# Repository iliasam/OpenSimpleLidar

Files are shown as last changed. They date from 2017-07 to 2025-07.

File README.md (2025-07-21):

# OpenSimpleLidar
Open Hardware scanning laser rangefinder.  
Its parameters:  
* 5 scans/second
* 180 measurements per rotation (2 deg anglular resolution)
* Maximum distance - 4 m
* Measured accuracy ~3-5 cm at 3 m (depends upon the color of reflecting surface).

This device is really cheap - its components cost less than $30.  
**UPD from 2023: Cost of the image sensor TSL1401CL increased very much, so total price can be higher!**  
See "TotalBOM" with price calculations.  
  
See project wiki for more info: https://github.com/iliasam/OpenSimpleLidar/wiki  

[Please take the simple survey about assembling instructions](https://docs.google.com/forms/d/127PN3ydydF8poReQAPeC-vXDqIst-CIAj8u08tnh1lM)  
  
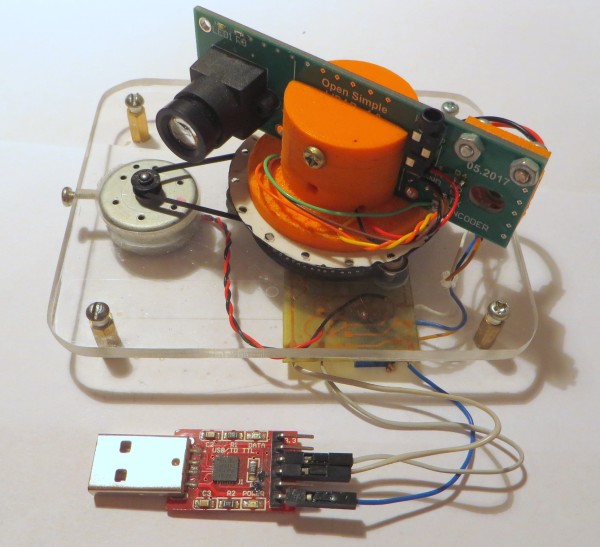
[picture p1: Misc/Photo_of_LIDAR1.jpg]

  
Utility for displaying "radar" scans from the working Lidar:  
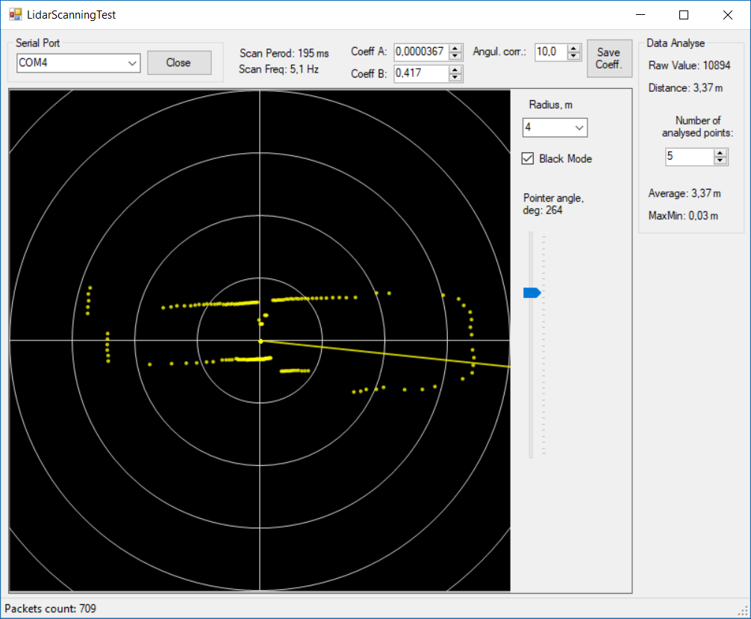
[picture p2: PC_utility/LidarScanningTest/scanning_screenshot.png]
  

Example of Hector SLAM working with this Lidar:  
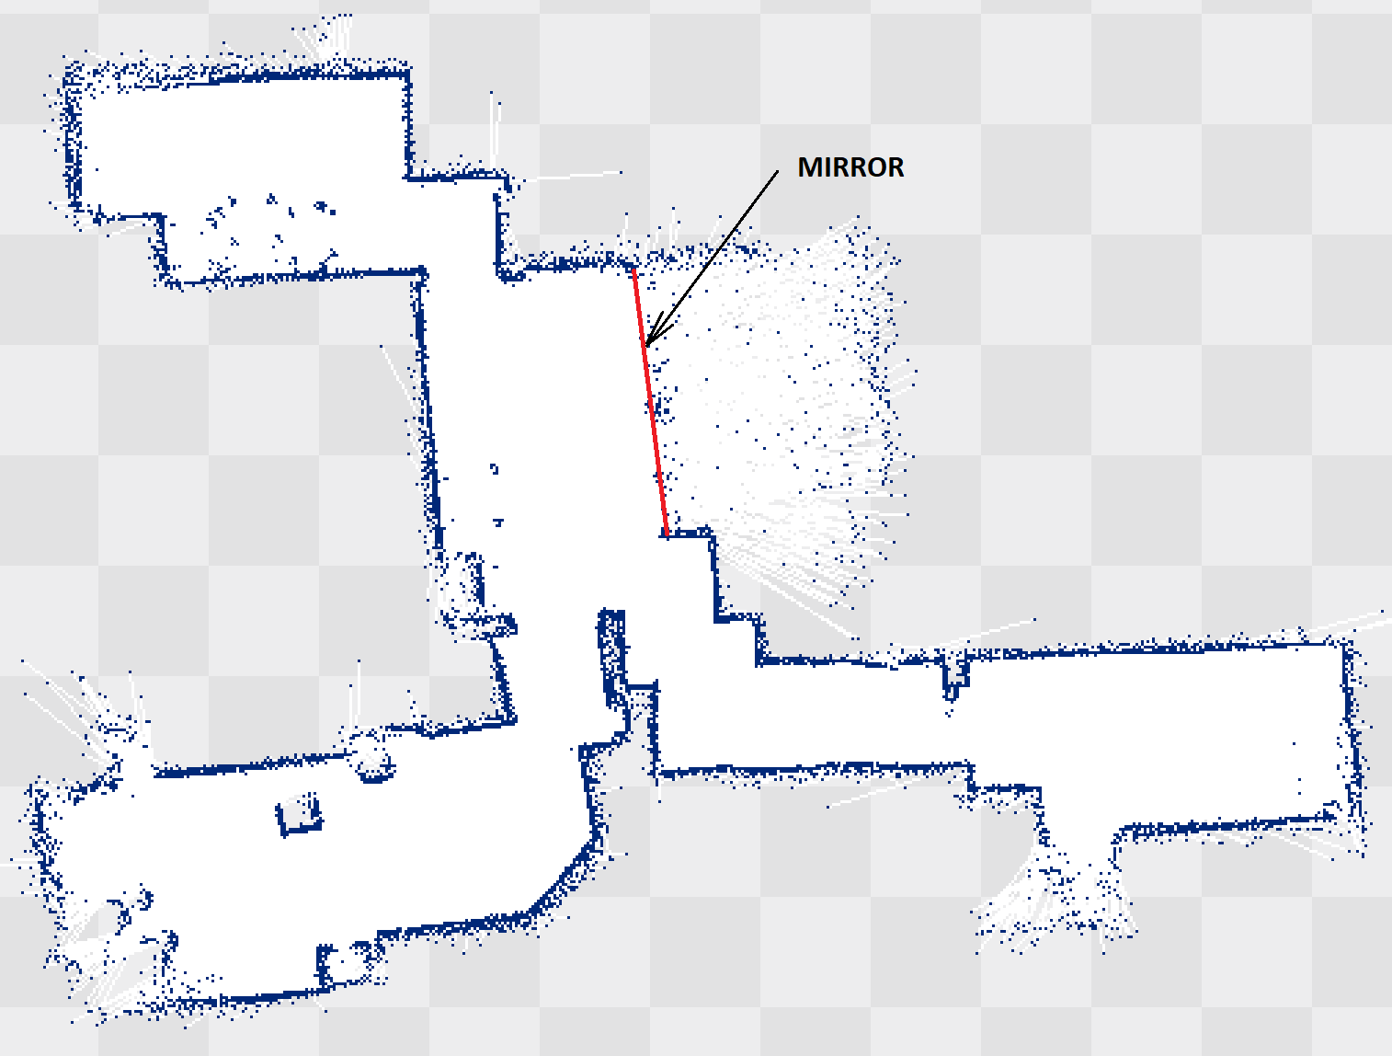
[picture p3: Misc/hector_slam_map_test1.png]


This Lidar is using **triangulation method** for measuring distance to objects. It can be shown by this picture:  
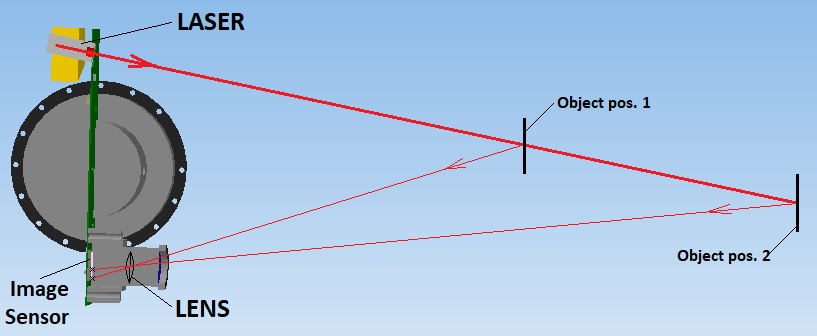
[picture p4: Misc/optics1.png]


Some modeled pictures of the assembled Lidar can be found here: https://github.com/iliasam/OpenSimpleLidar/tree/master/Misc/Pictures/  

Some more info: https://hackaday.io/project/20628-opensimplelidar  

Video of using OpenSimpleLidar for Autonomous Robot Navigation:  
https://www.youtube.com/watch?v=YHt_NTktmlA

See also my previous LIDAR project: https://github.com/iliasam/OpenLIDAR  
If you need LIDAR with increased speed and range, see this project: https://github.com/iliasam/OpenTOFLidar  

Please leave your feedback if you will be able to build this Lidar - I need more feedback about assembing instructions.

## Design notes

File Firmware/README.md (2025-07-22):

"test_encoder_blinking" - Testing code - link LED several times after power up, and then blinking LED when encoder event occurs.   
"test1_capture_image" - Testing code - capture image from linear image sensor and send it to PC.  
"test2_capture_image" - Testing code - the same as "test1_capture_image" but laser is ON most of the time. This is MORE dangerous for eyes than "test1_capture_image"!  
"lidar4_main_code" - Main LIDAR firmware.  

UART protocols are described here: https://github.com/iliasam/OpenSimpleLidar/wiki/Lidar-UART-Protocol  
  
IAR 7.50 could be used for building projects.  
You can find already build HEX files at the "EWARM/Output/Exe" folders.

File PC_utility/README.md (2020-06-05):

"LidarRawDataCapture.exe" - utility for displaying raw data from the TSL1401. This utility must be used with "test1_capture_image" firmware. It is needed during laser alignment.
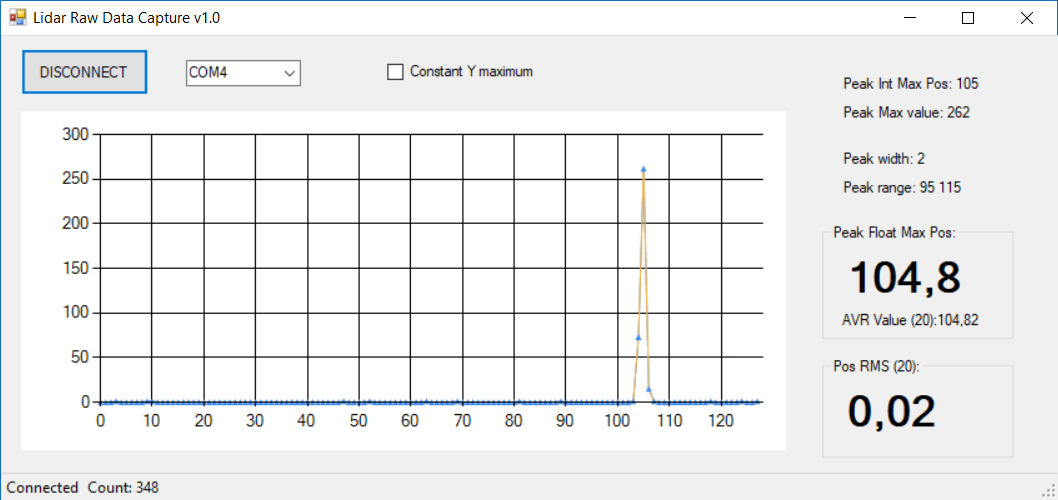
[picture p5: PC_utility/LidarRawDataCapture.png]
  

"LidarScanningTest" - utility for displaying "radar" scans from the working Lidar. This utility must be used with "lidar4_main_code" firmware.  
  

Values "Coeff A", "Coeff B" are calibration values. They are unique for every device.  
Track bar allows to set "Pointer angle" - angle of the long yellow line.  
Parameters of the point with that angle are displayed at "Data Analyse" group.  
This utility is published with its source files.  
"Exe" is placed here: https://github.com/iliasam/OpenSimpleLidar/tree/master/PC_utility/LidarScanningTest/LidarScanningTest1/bin/Debug

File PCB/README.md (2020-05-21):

## OpenSimpleLidar PCB and schematic.  
Important notice: I did not tested "CommonPCB_v1.1M", "CommonPCB_v1.2"  "MainPCB_v1.1"!  

Boards "MainPCB_v1.0"/"MainPCB_v1.1" should be used with "MotorPCB_v1.0".  

Board "CommonPCB_XX.XX" contains motor board, so you must split motor board and main board (by cutting by white line).  
Total width of the "CommonPCB_XX.XX" is 99mm, height is 26mm.  
PCB thickness - 1.6 mm.  
Board "CommonPCB_v1.2" have improved connections for the slip ring wires - now they are holes.  
Board "CommonPCB_v1.2M" - version for M12 lens holder with 20mm hole distance.  

## Схема и печатная плата OpenSimpleLidar
Внимание - я не изготавливал версии плат "CommonPCB_v1.1M" и "MainPCB_v1.1"!
Платы "MainPCB_v1.0" и "MainPCB_v1.1" нужно использовать с отдельной платой "MotorPCB_v1.0".  
Плата "CommonPCB_v1.1M" уже содержит в себе плату мотора, 
так что плату мотора нужно аккуратно отрезать от главной платы перед сборкой.
Общая ширина платы "CommonPCB_v1.1M" - 99 мм, высота - 26 мм.  
Толщина платы - 1.6 мм.

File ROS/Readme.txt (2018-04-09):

"roomba_lidar" is Open Hardware Lidar node for ROS.

Important notice - you need to specify "a_coef" and "b_coef" in *.launch file. This parameters calculated during lidar calibration.
Also you need to specify "port" parameter.

This code is partially taken from this project: http://wiki.ros.org/xv_11_laser_driver/

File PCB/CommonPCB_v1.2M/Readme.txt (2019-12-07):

Project files - PCB and schematic.  
Note that I don't test them.
V1.2M - version for M12 lens holder with 20mm hole distance.
There are no changes in schematic against "v1.2" PCB.
See assembling pictures in "CommonPCB_v1.2" folder.

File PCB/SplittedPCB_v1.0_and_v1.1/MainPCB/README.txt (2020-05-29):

Main board PCB.   
Gerber_files_v1.0 - 05.2017  
Gerber_files_v1.1 - 03.2018  
Important notice - I did not tested PCB v 1.1!

v1.1 differences from v1.0:
* Added J2 connectror fo programming via SWD.
* Added TEST2 pad

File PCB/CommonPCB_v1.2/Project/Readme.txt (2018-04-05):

Project files - PCB and schematic.  
Note that I don't test them.

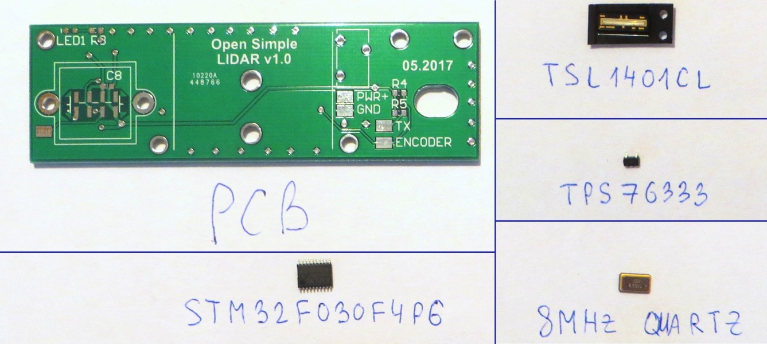
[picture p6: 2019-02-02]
Misc/Pictures/pcb_electronics.jpg

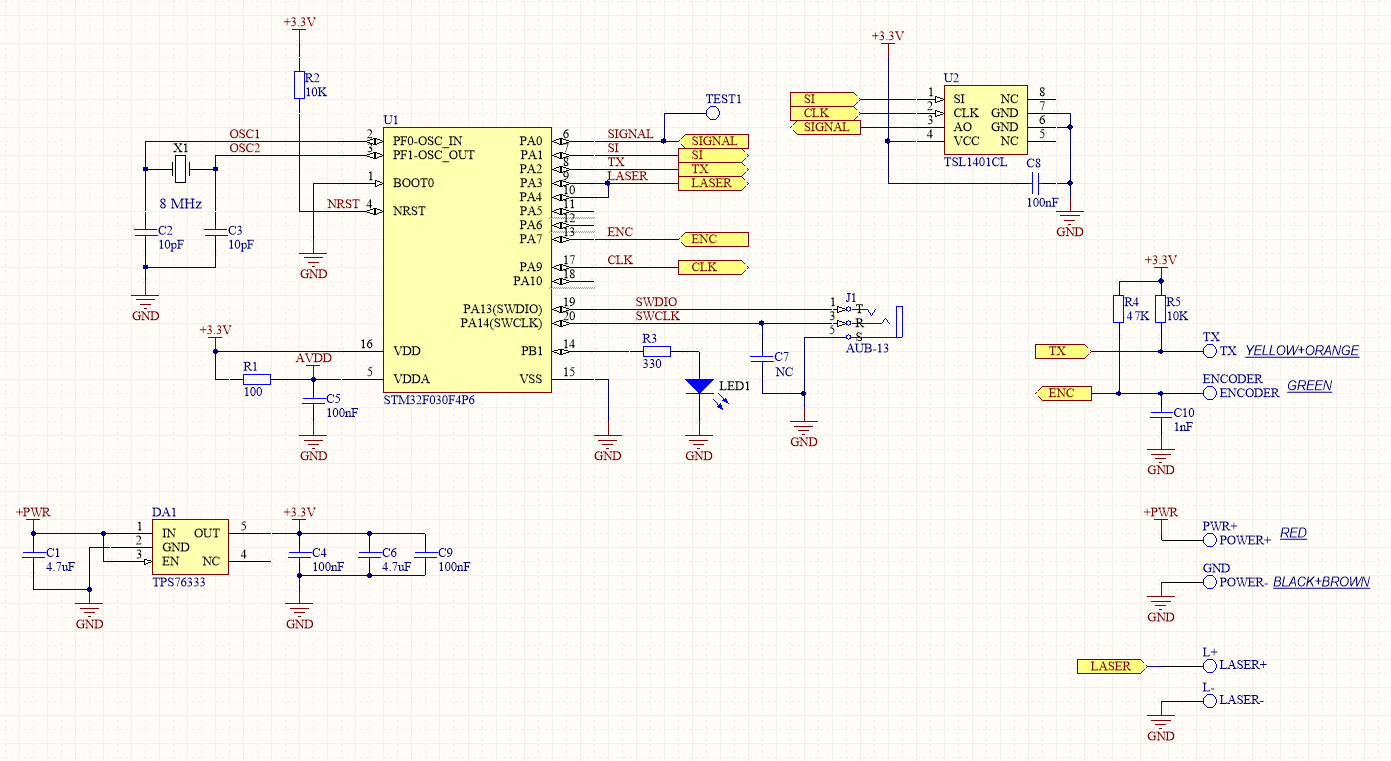
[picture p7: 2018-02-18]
PCB/SplittedPCB_v1.0_and_v1.1/MainPCB/Schematic_v1.png

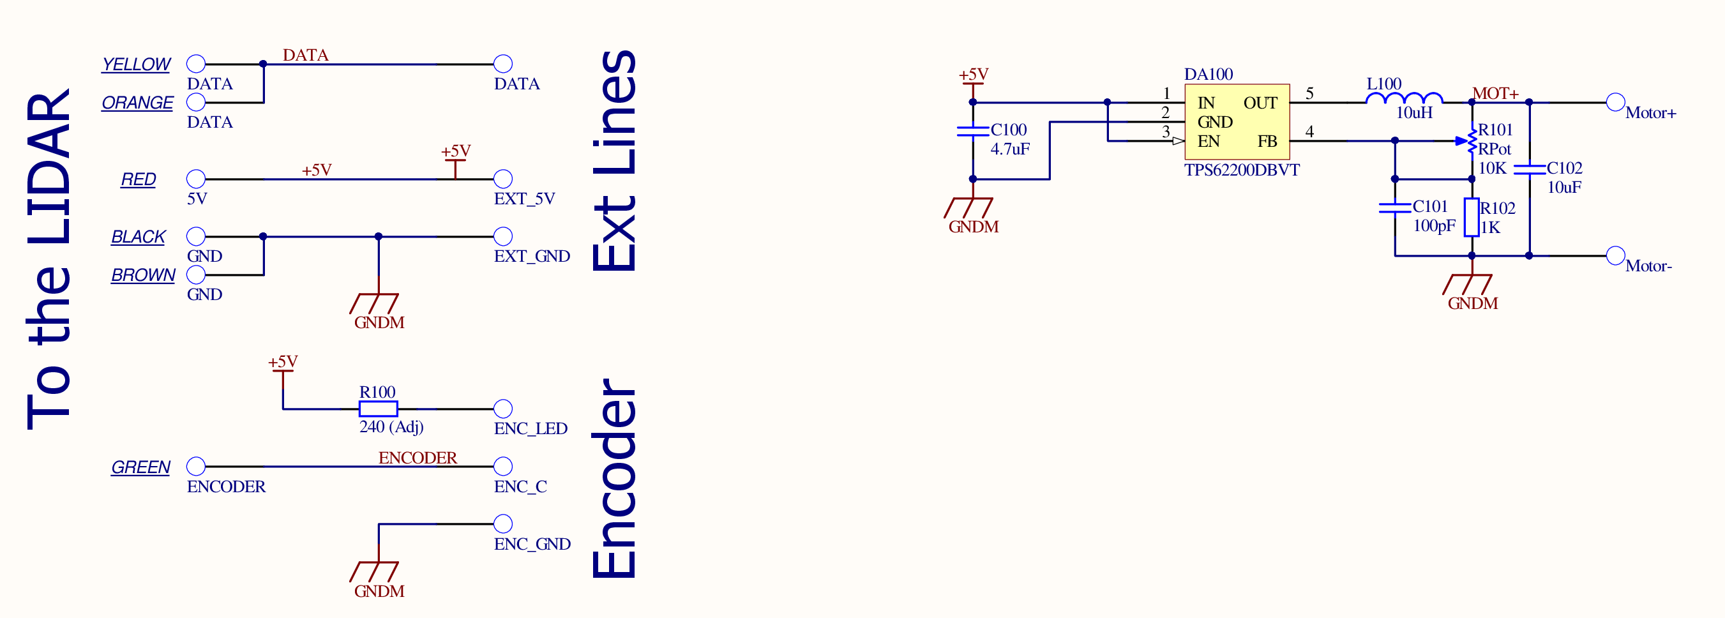
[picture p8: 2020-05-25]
PCB/CommonPCB_v1.2/Schematic_motor_v1.2.png

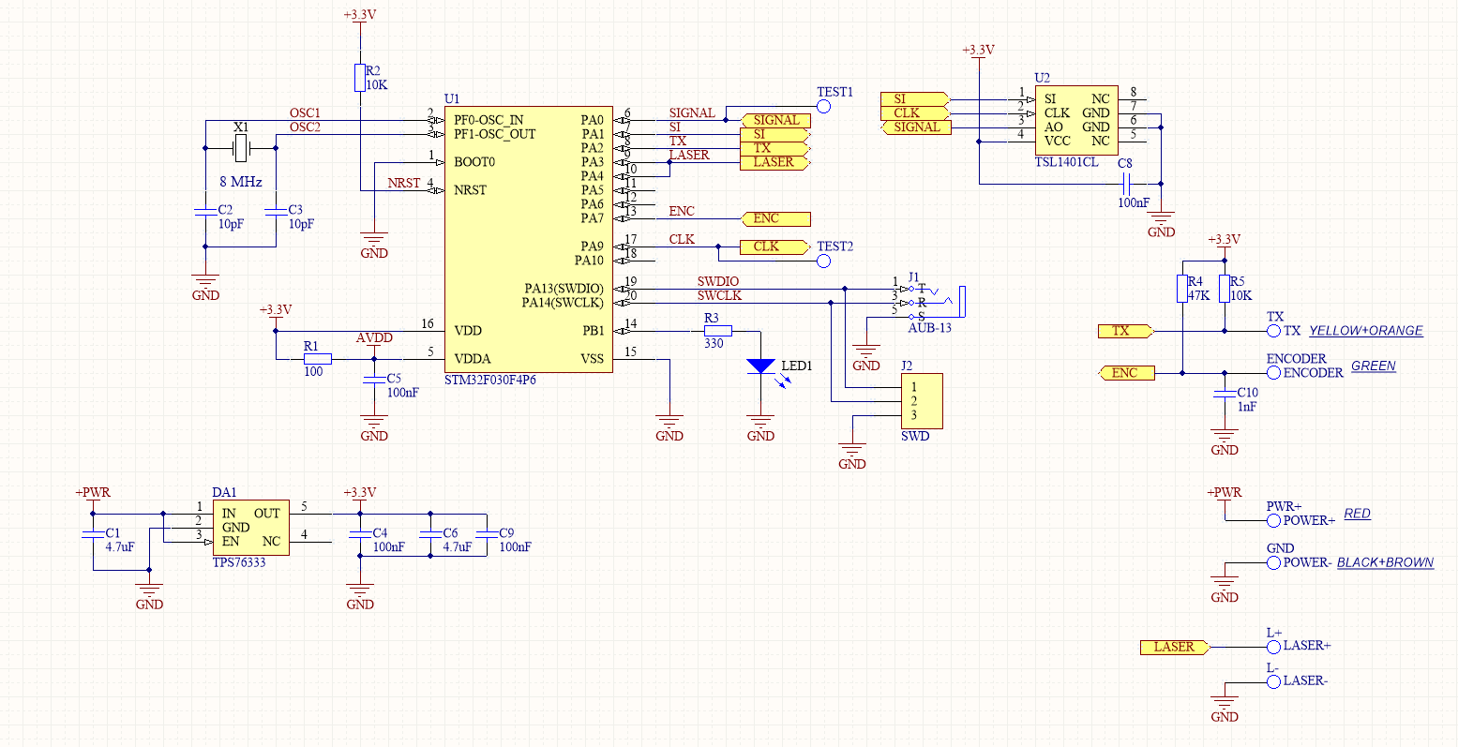
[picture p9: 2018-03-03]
PCB/SplittedPCB_v1.0_and_v1.1/MainPCB/Schematic_v1_1.png

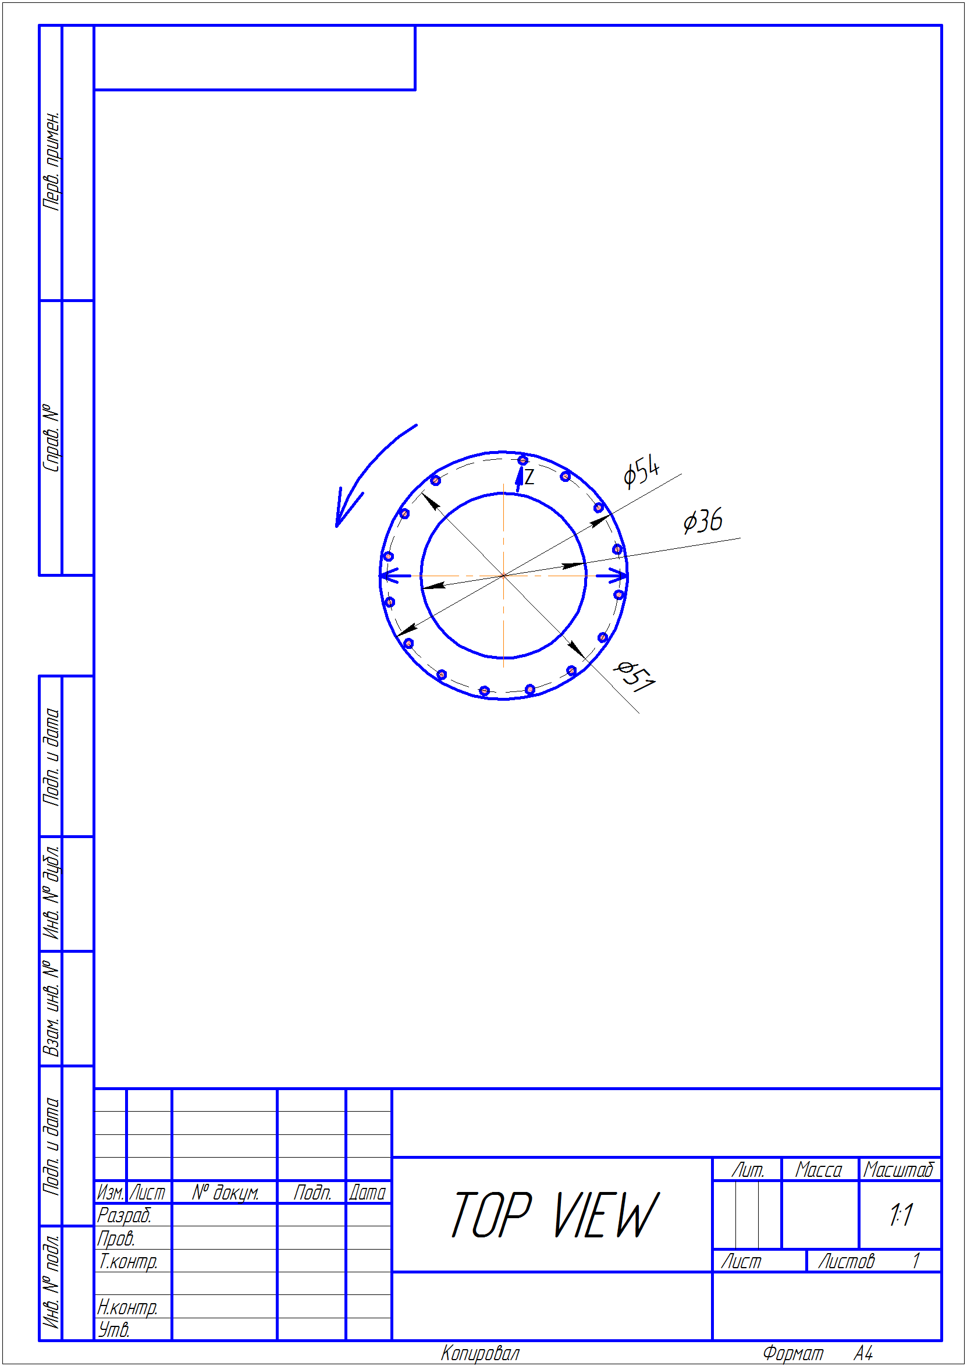
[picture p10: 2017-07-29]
Mechanics/Encoder_ring/Encoder_ring.png

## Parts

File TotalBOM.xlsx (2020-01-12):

 | No. | Name | Price | Description | URL
PCB components | 1 | Laser | $2.75 | 3mw 780nm Infrared IR Diode | http://www.ebay.com/itm/322300023463
 | 2 | Lens | $4.00 | M12 lens, f'=16mm, 1/3'', F2.0 | https://world.taobao.com/item/4526951102.htm
 | 3 | Interference filter (OPTIONAL) | $6.00 | 780nm IR Bandpass filter 8.0*8.0mm | http://www.ebay.com/itm/2pcs-Optical-Interference-Filter-780nm-IR-Bandpass-filter-8-0-8-0mm-/252299157201
 | 4 | Lens holder | $0.50 | M12 Lens holder (18 mm) | https://world.taobao.com/item/19038223269.htm
 |  |  |  | OR M12 Lens holder (20 mm) | for "CommonPCB_v1.2M"
 | 5 | PCB | $2.00 | Main PCB board - 1.6mm 2 layers. Price for 10 boards. | https://jlcpcb.com/quote
 | 6 | TSL1401CL | $6.00 | Image sensor | https://www.aliexpress.com/
 | 7 | MCU | $0.60 | STM32F030F4P6 - price for single chip. | https://www.aliexpress.com/item/Free-shipping-10pcs-STM32F030F4P6-Value-line-ARM-based-32-bit-MCU-STM32F030F4P6/32399890554.html
 | 9 | Slip Ring | $2.82 | 12.5mm 300Rpm 6 Wires Slip Ring (SRM-12-06a) | http://www.ebay.com/itm/141871384929
 | 10 | Motor | $1.00 | 3V DC motor
 | 11 | Ball bearing | $1.00 | 806ZZ type
 | 12 | Encoder sensor | $1.50 | RPI-352
 | 13 | Rubber belt | $1.00 | 150 mm - perimeter length
 | 14 | Pulley for motor |  | It could be taken form DVD
 |  | Total: | $29.17 | Note - this total price is calculated without delivery price
 |  |  | $23.17 | Price without filter

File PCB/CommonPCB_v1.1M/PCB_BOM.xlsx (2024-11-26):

Designator | Comment | Footprint | Description
C1 | 4.7uF | CAPC2012X135N | Chip capacitor
C2 | 10pF | CAPC1608X90N | Chip capacitor
C3 | 10pF | CAPC1608X90N | Chip capacitor
C4 | 100nF | CAPC1608X90N | Chip capacitor
C5 | 100nF | CAPC1608X90N | Chip capacitor
C6 | 4.7uF | CAPC2012X135N | Chip capacitor
C8 | 100nF | CAPC1608X90N | Chip capacitor
C9 | 100nF | CAPC1608X90N | Chip capacitor
C10 | 1nF | CAPC1608X90N | Chip capacitor
DA1 | TPS76333 | SOT23-5 | LDO
J1 | Jack 3.5 | AUB-13 | SWD connector
J2 | Header |  | Header, 3-Pin
LED1 | LED | 0603 | LED
R1 | 100 | RESC1608X55N | Chip resistor
R2 | 10K | RESC1608X55N | Chip resistor
R3 | 330 | RESC1608X55N | Chip resistor
R4 | 47K | RESC1608X55N | Chip resistor
R5 | 10K | RESC1608X55N | Chip resistor
U1 | STM32F030F4P6 | TSSOP65P640X120-20N | ARM-based 32-bit MCU
U2 | TSL1401CL | TSL1401CL | Light sensor
X1 | Quartz 8 MHz | SX-6 QUARTZ | Quartz_SX-6 (SMD06035C4)
Motor PCB
C100 | 4.7uF | CAPC2012X135N | Chip capacitor
C101 | 100pF | CAPC1608X90N | Chip capacitor
C102 | 10uF | CAPC3216X100N | Chip capacitor
L100 | Inductor 10uH | INDC3216 | Inductor
R100 | 240 Ohm (Adj) | RESC1608X55N | Chip resistor
R101 | Potentiometer 10K | VR5 | Potentiometer
R102 | 1K | RESC1608X55N | Chip resistor
DA100 | TPS62200DBVT | SOT23-5 | DC-DC step-down

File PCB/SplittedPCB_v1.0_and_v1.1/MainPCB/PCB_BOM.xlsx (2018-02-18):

# | Quantity | Designator | Footprint | Value | Description
1 | 2 | C1, C6 | CC0805 | 4.7uF | Chip capacitor
2 | 2 | C2, C3 | CC0805 | 10pF | Chip capacitor
3 | 4 | C4, C5, C8, C9 | CC0805 | 100nF | Chip capacitor
4 | 1 | C7 | CC0805 | NC | Chip capacitor
5 | 1 | DA1 | SOT23-5 | TPS76333 | LDO
6 | 1 | ENCODER |  | ENCODER | Pad for wire
7 | 1 | GND |  | POWER- | Pad for wire
8 | 1 | J1 | AUB-13 | AUB-13 | Programming connector
9 | 1 | L+ | Ext_hole | LASER+ | Pad for wire
10 | 1 | L- | Ext_hole | LASER- | Pad for wire
11 | 1 | LED1 | LED_0603 | LED
12 | 1 | PWR+ | Ext_pad | POWER+ | Pad for wire
13 | 1 | R1 | RC0805 | 100 | Chip resistor
14 | 2 | R2, R5 | RC0805 | 10k | Chip resistor
15 | 1 | R3 | RC0805 | 330 | Chip resistor
16 | 1 | R4 | RC0805 | 47k | Chip resistor
17 | 1 | TEST1 | Ext_pad | Pad | Pad for wire
18 | 1 | TX | Ext_pad | TX | Pad for wire
19 | 1 | U1 | TSSOP65P640X120-20N | STM32F030F4P6 | MCU
20 | 1 | U2 | TSL1401CL | TSL1401CL | Light sensor
21 | 1 | X1 | SX-6 QUARTZ | Quartz | Quartz_SX-6 (SMD06035C4)

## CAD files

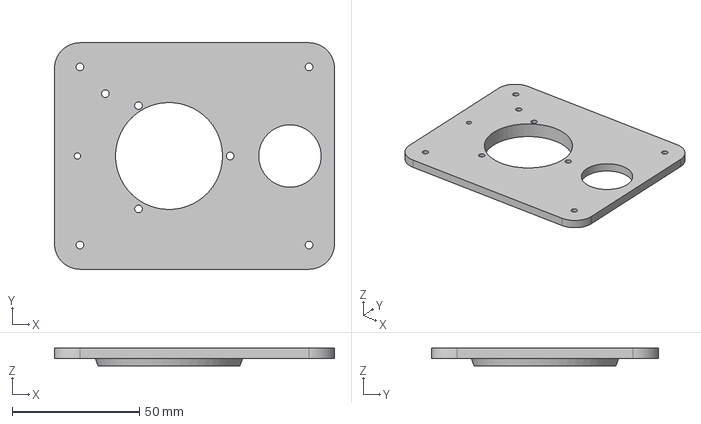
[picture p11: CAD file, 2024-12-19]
Mechanics/3D_models/plate_for_printing.stp
110.0 x 89.0 x 7.00 mm

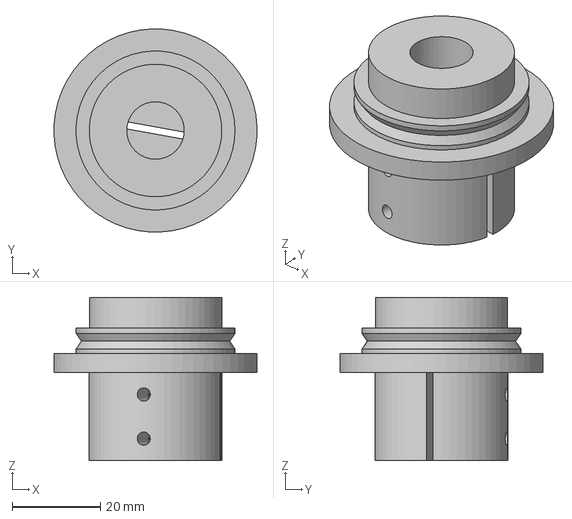
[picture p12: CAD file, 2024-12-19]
Mechanics/3D_models/holder_v1.0.stp
46.0 x 46.0 x 37.0 mm

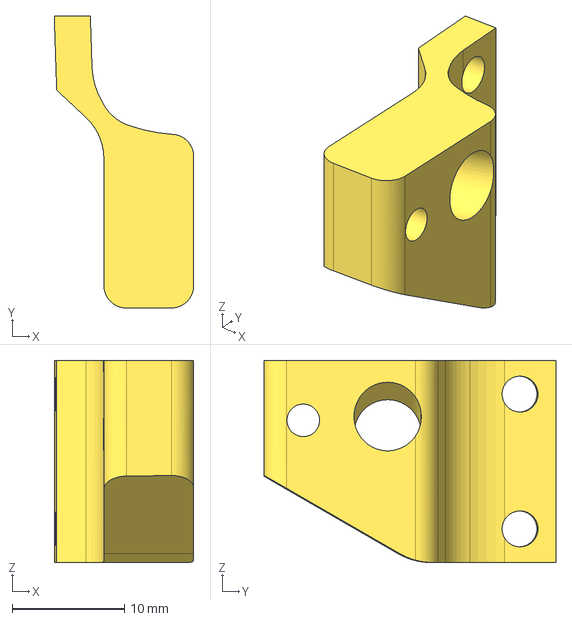
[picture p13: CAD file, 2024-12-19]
Mechanics/3D_models/laser_holder1_step.stp
12.4 x 26.0 x 18.0 mm

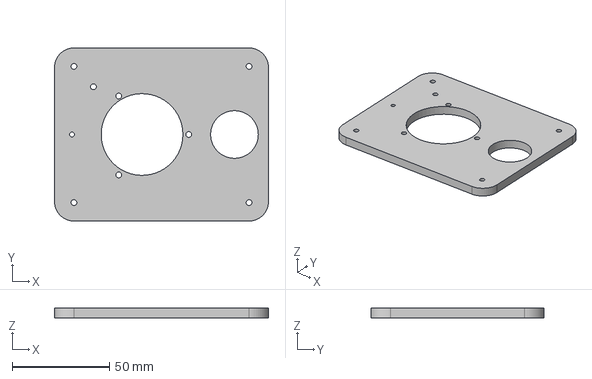
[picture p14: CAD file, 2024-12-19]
Mechanics/3D_models/plate_for_cut.stp
110.0 x 89.0 x 5.00 mm

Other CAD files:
Mechanics/Base_plate/base_plate.dxf
Mechanics/Encoder_ring/Encoder_ring.dxf
Mechanics/3D_models/plate_for_cut_v1.0.stl
Mechanics/3D_models/plate_for_printing_v1.0.stl
Mechanics/3D_models/laser_holder_v1.0.stl
Mechanics/3D_models/holder_v1.0.stl

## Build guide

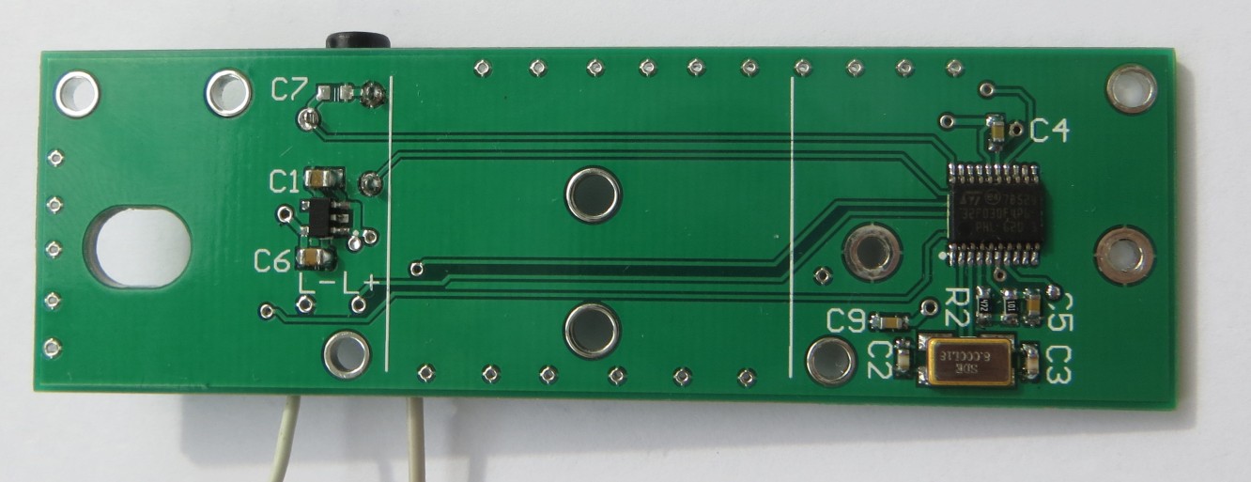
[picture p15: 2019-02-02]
Misc/Pictures/pcb_assembled.JPG

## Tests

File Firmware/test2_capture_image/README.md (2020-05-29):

"test2_capture_image" - Testing code - the same as "test1_capture_image" but laser is ON most of the time.  
This is MORE dangerous for eyes than is "test1_capture_image"!  
"StdPeriphLib" is not included to the Git, take it from "test1_capture_image".  
There is already build "Firmware.hex" here.

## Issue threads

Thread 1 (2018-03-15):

Where to get Lidar?

akhilesh-k, 2018-03-15:
This isn't exactly an issue, but I was curious from where to buy this lidar module. I coudn't find any single place where lidar is being sold at this price.
It would be great if you can help with using hardware modules.

iliasam, 2018-03-15:
It does not sold - there is no production on this Lidars.
> it's **components** cost less than $35.

akhilesh-k, 2018-03-15:
Hello iliasam,
Many thanks for replying.
I want to explore in fields of self driving cars so this is important for me. Can you suggest how to reproduce such a laser rangefinder with minimum cost.

Regards,

Akhilesh Kumar

Sophomore,

Major: Electronics and Communication Engineering
Jaypee University of Information Technology, Waknaghat

mail: akhilesh_k@outlook.com

https://akhilesh-k.github.io

________________________________
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

Closed 2018-03-18.

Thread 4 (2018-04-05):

Gerbers are not source

Snowda, 2018-04-05:
Currently the PCB files are provided in gerber file format which are only used as input for manufacturing. These are generated output, not actual reasonably easy to modify _original_ source files. If I want to go round off some corners (for example) it's really not worth the sheer amount of effort that would be needed to modify them.

Native Eagle, Altium, KiCad, etc. files would be much easier to access. Until that happens, I wouldn't be exactly referring to this as "open".

iliasam, 2018-04-05:
OK, I will add project files soon.

iliasam, 2018-04-05:
I have added project files for the "CommonPCB".

Closed 2018-04-07.

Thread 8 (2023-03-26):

CPL file?

ajsnyde, 2023-03-26:
Sorry, noob question. Not sure what I should give for a CPL file when ordering through jlcpcb:
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

iliasam, 2023-03-26:
This project is not designed for assembling at the factory, and I don't have files for that.
Also this PCB has components at both sides, while JLCPCB can install components only at the one side.

ajsnyde, 2023-03-26:
Ah! Ok, that makes sense! I'll order and assemble it myself. Saw they had a promotion for free assembly and thought that was the "right" way to do it. Thanks man!

Closed 2023-03-26.

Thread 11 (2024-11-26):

Likely problem with R102

HaroldSapientia, 2024-11-26:
In the BOM, R102 is 10k. But in the pcb design file it's 1k. What exactly it should be?

iliasam, 2024-11-26:
It must be 10k, thanks for feedback!

iliasam, 2024-11-26:
Sorry, I'm mistaken, it should be 1k as at the schematic.
I had updated all BOMs.

HaroldSapientia, 2024-11-27:
An additional problem, I'm a freshman. What does 240 ohms (adj) for R100 mean? Thank you！

iliasam, 2024-11-27:
This resistor is limiting current of encoder LED.
I had updated the schematic: https://github.com/iliasam/OpenSimpleLidar/blob/master/PCB/CommonPCB_v1.2M/Schematic_motor_v1.2.png

Closed 2024-12-19.

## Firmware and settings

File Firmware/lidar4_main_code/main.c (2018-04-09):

//Open Simple Lidar v4
//Main LIDAR code
//by ILIASAM

//Main configuration values are placed at "main.h"

/* Includes ------------------------------------------------------------------*/
#include "main.h"

#include "init_periph.h"
#include "uart_handler.h"
#include <stdio.h>

int putchar(int c);

void uart_send_captured_data(void);

int main(void)
{
  //Core frequency - 48MHz
  init_clk();
  
  RCC_ClocksTypeDef RCC_Clocks;
  RCC_GetClocksFreq (&RCC_Clocks);
  SysTick_Config(RCC_Clocks.HCLK_Frequency / SYSTICK_FREQUENCY);
  
  init_all_periph();
  
  while (1)
  {
     process_handler();
  }
}


int putchar(int c)
{
  USART_SendData(USART1, c);
  while(USART_GetFlagStatus(USART1, USART_FLAG_TXE) == RESET );
  return c;
}

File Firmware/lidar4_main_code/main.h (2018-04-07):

/**
  ******************************************************************************
  * @file    Project/STM32F0xx_StdPeriph_Templates/main.h 
  * @author  MCD Application Team
  * @version V1.5.0
  * @date    05-December-2014
  * @brief   Header for main.c module
  ******************************************************************************
  * @attention
  *
  * <h2><center>&copy; COPYRIGHT 2014 STMicroelectronics</center></h2>
  *
  * Licensed under MCD-ST Liberty SW License Agreement V2, (the "License");
  * You may not use this file except in compliance with the License.
  * You may obtain a copy of the License at:
  *
  *        http://www.st.com/software_license_agreement_liberty_v2
  *
  * Unless required by applicable law or agreed to in writing, software 
  * distributed under the License is distributed on an "AS IS" BASIS, 
  * WITHOUT WARRANTIES OR CONDITIONS OF ANY KIND, either express or implied.
  * See the License for the specific language governing permissions and
  * limitations under the License.
  *
  ******************************************************************************
  */
  
/* Define to prevent recursive inclusion -------------------------------------*/
#ifndef __MAIN_H
#define __MAIN_H

/* Includes ------------------------------------------------------------------*/
#include "stm32f0xx.h"

#include "encoder_handler.h"
#include "laser_handler.h"
#include "uart_handler.h"
#include "init_periph.h"

//Number of the pixels in TSL1401
#define CAPTURED_POINTS_CNT     128

//Measurement every 2 deg - 180 points per rotation
//This helps to increase speed twice
#define TWO_DEG_MODE    


//Length of packet in halfwords (2 bytes)
//360 data + 2 header + 1 status flags + 1 speed
#define PACKET_OFFSET (uint16_t)(2+1+1)
#define PACKET_LENGTH (uint16_t)(360+PACKET_OFFSET)

//Number of encoder marks (holes)
#define ENC_NUM                 15     

#define UART_BAUDRATE           115200

#define SYSTICK_FREQUENCY       1000 //Hz
    
//Emulating encoder for debug purposes
//#define ENABLE_ENCODER_EMULATION
    
#ifdef ENABLE_ENCODER_EMULATION
    
#define VIRTUAL_ROTATION_SPEED  4 //Rotation per second
#define VIRTUAL_ROTATION_PERIOD (1000 /  VIRTUAL_ROTATION_SPEED) //1000ms in one sec
    
//Perio of the emulated encoder
#define VIRTUAL_ENCODER_PERIOD  (VIRTUAL_ROTATION_PERIOD / ENC_NUM)

#endif


/* Exported types ------------------------------------------------------------*/
/* Exported constants --------------------------------------------------------*/
/* Exported macro ------------------------------------------------------------*/
/* Exported functions ------------------------------------------------------- */

#endif /* __MAIN_H */

/************************ (C) COPYRIGHT STMicroelectronics *****END OF FILE****/

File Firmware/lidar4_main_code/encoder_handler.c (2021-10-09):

#include "main.h"
#include "encoder_handler.h"
#include "stdio.h"

//Used for speed sensor
volatile uint16_t capture_old = 0;
volatile uint16_t capture_now = 0; //Captured time (in "ENC_TIM" ticks)
volatile uint16_t time_tmp = 0; //Time of rotating for 1 deg (in "ENC_TIM" ticks)
volatile uint8_t  rot_num  = 0; //Number of encoder events
volatile uint16_t rot_period  = 0; //Disc rotation period (in ms)
volatile uint16_t enc_period; //Time between encoder events (in "ENC_TIM" ticks)

volatile uint8_t overspeed_flag   = 0; //1 - speed is too high
volatile uint8_t sync_failed_flag = 0; //1 - sync error - error at counting encoder marks

volatile uint16_t cap_number = 0;//Number of sampled points
extern volatile meas_status_type meas_status;//Status of capturing 3 images

uint16_t get_encoder_timer_value(void);

//TIM16 Compare interrupt - every 1 deg of rotation
//used for starting image capture
void TIM16_IRQHandler(void)
{
  if (TIM_GetITStatus(DEGREE_TIM_NAME, TIM_IT_CC1) != RESET)
  {
    TIM_ClearITPendingBit(ENC_TIM_NAME, TIM_IT_CC1);
    DEGREE_TIM_NAME->SR &= ~TIM_SR_CC1IF;//Clear interrupt flag
    if (cap_number < 359)
    {
	  //Start capturing new degree - from a zero phase
      meas_status = PHASE_WAIT;
      cap_number++;
#ifdef TWO_DEG_MODE
  cap_number++;
#endif
      switch_adc_buf();
      meas_handler(); //Start capture
    }
  }
}

//TIM17 Input Capture interrupt - from the encoder
void TIM17_IRQHandler(void)
{

  volatile static uint16_t zero_old = 0;
  volatile static uint16_t zero_now = 0;

#ifdef ENABLE_ENCODER_EMULATION
  if (1)
  {
#else
  if (TIM_GetITStatus(ENC_TIM_NAME, TIM_IT_CC1) != RESET)
  {
#endif
    TIM_ClearITPendingBit(ENC_TIM_NAME, TIM_IT_CC1);
    capture_old = capture_now;
    capture_now = get_encoder_timer_value();
    uint16_t capture_old_non_volatile = capture_old;

    //Overflow controlling
    if (capture_now >= capture_old_non_volatile)
      enc_period = capture_now - capture_old_non_volatile;
    else
      enc_period = 0xFFFF - capture_old_non_volatile + capture_now;

#ifdef TWO_DEG_MODE
    if (enc_period < (MIN_ENC_TIME / 2))
    {
      switch_led(1);
      enc_period = (MIN_ENC_TIME / 2);
      overspeed_flag = 1;
    }
#else
    if (enc_period < MIN_ENC_TIME)
    {
      switch_led(1);
      enc_period = MIN_ENC_TIME;
      overspeed_flag = 1;
    }
#endif
    else
    {
      switch_led(0);
      overspeed_flag = 0;
    }

    time_tmp = enc_period / ENC_ARC_DEG; //time of the rotation for 1 deg

    rot_num++;
    cap_number = rot_num * ENC_ARC_DEG;

    if (check_zero_point(time_tmp) == 1) //Zero crossing detected
    {
      //"enc_period" here is doubled because of encoder construction
      enc_period = enc_period / 2;
      time_tmp = enc_period / ENC_ARC_DEG;

      zero_old = zero_now;
      zero_now = get_encoder_timer_value();
      uint16_t zero_old_non_volatile = zero_old;

      if (zero_now >= zero_old_non_volatile)
        rot_period = (zero_now - zero_old_non_volatile) / (TIMERS_FREQUENCY / KILO_CONST);
      else
        rot_period = (0xFFFF - zero_old_non_volatile + zero_now) / (TIMERS_FREQUENCY / KILO_CONST);

      if (rot_num != ENC_NUM)//(ENC_NUM-1) because of one absent mark
      {
        sync_failed_flag = 1;
        switch_led(1);
      }
      else
      {
        switch_led(0);
      }

      stop_capture();
      if (sync_failed_flag == 0)
      {
        start_send_result();//Encoder is working fine
      }
      //printf("%d\r\n", rot_num);
      sync_failed_flag = 0;
      rot_num = 0;
      cap_number = 0;
      //printf("zero %d\r\n", time_tmp);
      refresh_degree_timer(time_tmp-1);
    }
    else
    {
      //printf("%d\r\n", time_tmp);
      set_degree_timer_period(time_tmp-1);
    }
  }
}

//This timer is capturing events from the encoder
//Timer mode - input capture
void init_encoder_timer(void)
{
  TIM_TimeBaseInitTypeDef       TIM_TimeBaseStructure;

  NVIC_InitTypeDef              NVIC_InitStructure;
  GPIO_InitTypeDef              GPIO_InitStructure;

  RCC_APB2PeriphClockCmd(RCC_APB2Periph_TIM17, ENABLE);

  GPIO_InitStructure.GPIO_Mode  = GPIO_Mode_AF;//Data from the encoder
  GPIO_InitStructure.GPIO_Pin   = ENCODER_PIN;
  GPIO_InitStructure.GPIO_Speed = GPIO_Speed_2MHz;
  GPIO_InitStructure.GPIO_OType = GPIO_OType_PP;
  GPIO_InitStructure.GPIO_PuPd  = GPIO_PuPd_UP;
  GPIO_Init(ENCODER_PORT, &GPIO_InitStructure);
  GPIO_PinAFConfig(ENCODER_PORT, ENCODER_PIN_SRC, GPIO_AF_5);

  TIM_TimeBaseStructInit(&TIM_TimeBaseStructure);

  TIM_TimeBaseStructure.TIM_Prescaler   = ENC_TIM_PRESCALER;
  TIM_TimeBaseStructure.TIM_Period      = 0xFFFF;
  TIM_TimeBaseStructure.TIM_ClockDivision = TIM_CKD_DIV1;
  TIM_TimeBaseStructure.TIM_CounterMode = TIM_CounterMode_Up;
  TIM_TimeBaseInit(ENC_TIM_NAME, &TIM_TimeBaseStructure);

#ifndef ENABLE_ENCODER_EMULATION
  // channel1 - input capture - falling edge

  TIM_ICInitTypeDef             TIM_ICInitStructure;
  TIM_ICStructInit(&TIM_ICInitStructure);
  TIM_ICInitStructure.TIM_Channel       = TIM_Channel_1;
  TIM_ICInitStructure.TIM_ICPolarity    = TIM_ICPolarity_Falling;
  TIM_ICInitStructure.TIM_ICSelection   = TIM_ICSelection_DirectTI;
  TIM_ICInitStructure.TIM_ICPrescaler   = TIM_ICPSC_DIV1;
  TIM_ICInitStructure.TIM_ICFilter      = 15;//uart produce some noise
  TIM_ICInit(ENC_TIM_NAME, &TIM_ICInitStructure);

  TIM_ClearITPendingBit(ENC_TIM_NAME, TIM_IT_CC1);
  TIM_ITConfig(ENC_TIM_NAME, TIM_IT_CC1, ENABLE);

  NVIC_InitStructure.NVIC_IRQChannel            = TIM17_IRQn;
  NVIC_InitStructure.NVIC_IRQChannelPriority    = 15;
  NVIC_InitStructure.NVIC_IRQChannelCmd         = ENABLE;
  NVIC_Init(&NVIC_InitStructure);
#endif

  TIM_ARRPreloadConfig(TIM17, ENABLE);
  TIM_Cmd(ENC_TIM_NAME, ENABLE);
}
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

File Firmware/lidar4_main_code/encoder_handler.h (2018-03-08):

#ifndef _ENCODER_HANDLER_H
#define _ENCODER_HANDLER_H

#include "stm32f0xx.h"
#include "main.h"

#define ENC_TIM_NAME            TIM17
#define DEGREE_TIM_NAME         TIM16

#define TIMERS_FREQUENCY        50000 //Frequency of encoder timer and degree timer in Hz
#define KILO_CONST              1000

#define ENC_TIM_PRESCALER       (uint16_t)((SystemCoreClock / TIMERS_FREQUENCY) - 1)//APB1 = HCLK/2*2
#define DEGREE_TIM_PRESCALER    (uint16_t)((SystemCoreClock / TIMERS_FREQUENCY) - 1)//APB2 = HCLK


#define MAX_SPEED               (3.5f)//Maximum allowed rotation speed - in Hz
#define MIN_ENC_TIME            (uint16_t)((float)TIMERS_FREQUENCY / (MAX_SPEED * (ENC_NUM + 1)))//Minimum allowed time of encoder events
#define ENC_ARC_DEG             (uint16_t)(360 / (ENC_NUM + 1)) //Number of degrees in single encoder mark arc

void TIM16_IRQHandler(void);
void TIM17_IRQHandler(void);

void init_encoder_timer(void);
void init_degree_timer(void);
void refresh_degree_timer(uint16_t time);

uint8_t check_zero_point(uint16_t time);

void set_degree_timer_period(uint16_t period);

void emulated_encoder_timer_event(void);

#endif

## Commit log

2017-04-15 Added BOM.
    [TotalBOM.xlsx]
2017-06-18 Holder model added.
    [holder_v1.0.stp]
2017-06-18 Holder model updated.
    [holder_v1.0.stl, holder_v1.0.stp]
2017-06-18 PCB schematic and PCB gerber files added.
    [PCB1.GBL, PCB1.GBO, PCB1.GBS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]
2017-07-29 Some bin files are updated.
    [Encoder_ring.dxf, PCB_BOM.xlsx, holder_v1.0.stl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]
2017-09-16 Some changes in schematic, added firmware.
    [TotalBOM.xlsx]
2017-09-16 Photo of LIDAR was added.
2017-10-01 Added files of "Motor PCB", some drawings ad 3D models.
    [base_plate.dxf, plate_for_cut_v1.0.stl, plate_for_printing_v1.0.stl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]
2018-02-11 Small improvenents.
    [TotalBOM.xlsx]
2018-02-16 Schematic update.
2018-02-18 Corrected R4 value.
    [PCB_BOM.xlsx]
2018-02-23 Updated schematic.
2018-02-23 Files moved.
    [PCB_BOM.xlsx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]
2018-02-23 "LidarRawDataCapture" ulility has been added.
2018-03-03 Added updated mainPCB v1.1. Added assemble images.
    [PCB1.GBL, PCB1.GBO, PCB1.GBS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]
2018-03-04 Added CommonPCB_v1.1M - it contains motor board.
    [PCB1.GBL, PCB1.GBO, PCB1.GBS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]
2018-03-04 Small updates. Added BOM for CommonPCB_v1.1M.
    [PCB_BOM.xlsx]
2018-03-08 Some refactoring. Added encoder emulation.
2018-04-05 I have added project files for the "CommonPCB".
    [Lidar_PCB_Project.PrjPcb, PCB1.PcbDoc, lidar4_sch.SchDoc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]
2018-04-08 Added "CommonPCB_v1.2" with improved wire connections.
    [Lidar_PCB_Project.PrjPcb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]
2018-04-09 Change ROS driver to newer version. Added led blinking during start.
2018-04-10 Filter photo added.
2018-12-08 Updated TotalBOM.
    [TotalBOM.xlsx]
2019-12-07 Added 1.2M version.
    [Lidar_PCB_Project.PrjPcb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]
2020-01-12 BOM small update.
    [TotalBOM.xlsx]
2020-05-25 Corrected DC-DC resistors values mistake.
    [PCB1.PcbDoc, motor_sch.SchDoc]
2020-06-05 Added laser_angle file
2021-10-04 fix MISRA C warning - variable `DMA_InitStructure' clashes with global variable `DMA_InitStructure'
    [init_periph.c]
2021-10-04 Fix possible divide for zero and volatile warnings
    [encoder_handler.c]
2023-03-27 Documentation update.
    [PCB_BOM.xlsx]
2024-11-26 Updated R102 value.
    [PCB_BOM.xlsx]
2024-11-27 Updated schematic.of v1.2M
2024-12-19 Added STEP 3d files.
    [holder_v1.0.stp, laser_holder1_step.stp, plate_for_cut.stp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]
